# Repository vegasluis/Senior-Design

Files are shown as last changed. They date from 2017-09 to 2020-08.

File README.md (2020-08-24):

# Senior-Design

# Problem Identified
Pedestrian fatality rate is three times higher at night. Per the Traffic Safety Facts
(2012 Data), 70% of the pedestrians are killed in the nighttime (6PM – 5:59AM).
A driver can only avoid an accident if he/she sees the pedestrian relatively far
ahead. Headlights only let the driver see about 350 feet ahead.

# Current Solutions
The closest solution in the market is the innovative design Audi has incorporated
to their car model; the Audi A4 is more for personal use rather than a pubic
design. Crosswalk lighting on the street is available to light up sections of the
crosswalk once the light is pressed. Overhead flashing lights, like the Hawk
System, are also used with a set timer to warn drivers that pedestrians are trying
to cross. One tested solution is setting two posts on both sides of the street,
such that once a pedestrian presses a button, the lights turn on to illuminate the
crosswalk.

# Team’s Solution
The Pedestrian Lighting Guidance System is a more efficient way to solve
pedestrian fatalities due to poor visibility at night. The system will be very userfriendly. Pedestrians would not have to do anything different than they usually
do when crossing the street at night, because the pedestrian detection software
will control the spotlight whenever someone triggers it. The system will run
autonomously. The main detail of the
PLGS is its ability to view any object
crossing in the intersection using the
OpenCV libraries. The cameras process
the incoming images and relay the
position to the microprocessors that
control the motor servos, which rotate
180 degrees and will be able to move
the focused spotlights from one side of
the crosswalk to the other. The device
we are trying to create is optimized
more for industrial use, not for
consumer use. It does not require any
sort of reconstruction or modification
on the road.

# Youtube URL

https://www.youtube.com/watch?v=EUFnc7yAI7A

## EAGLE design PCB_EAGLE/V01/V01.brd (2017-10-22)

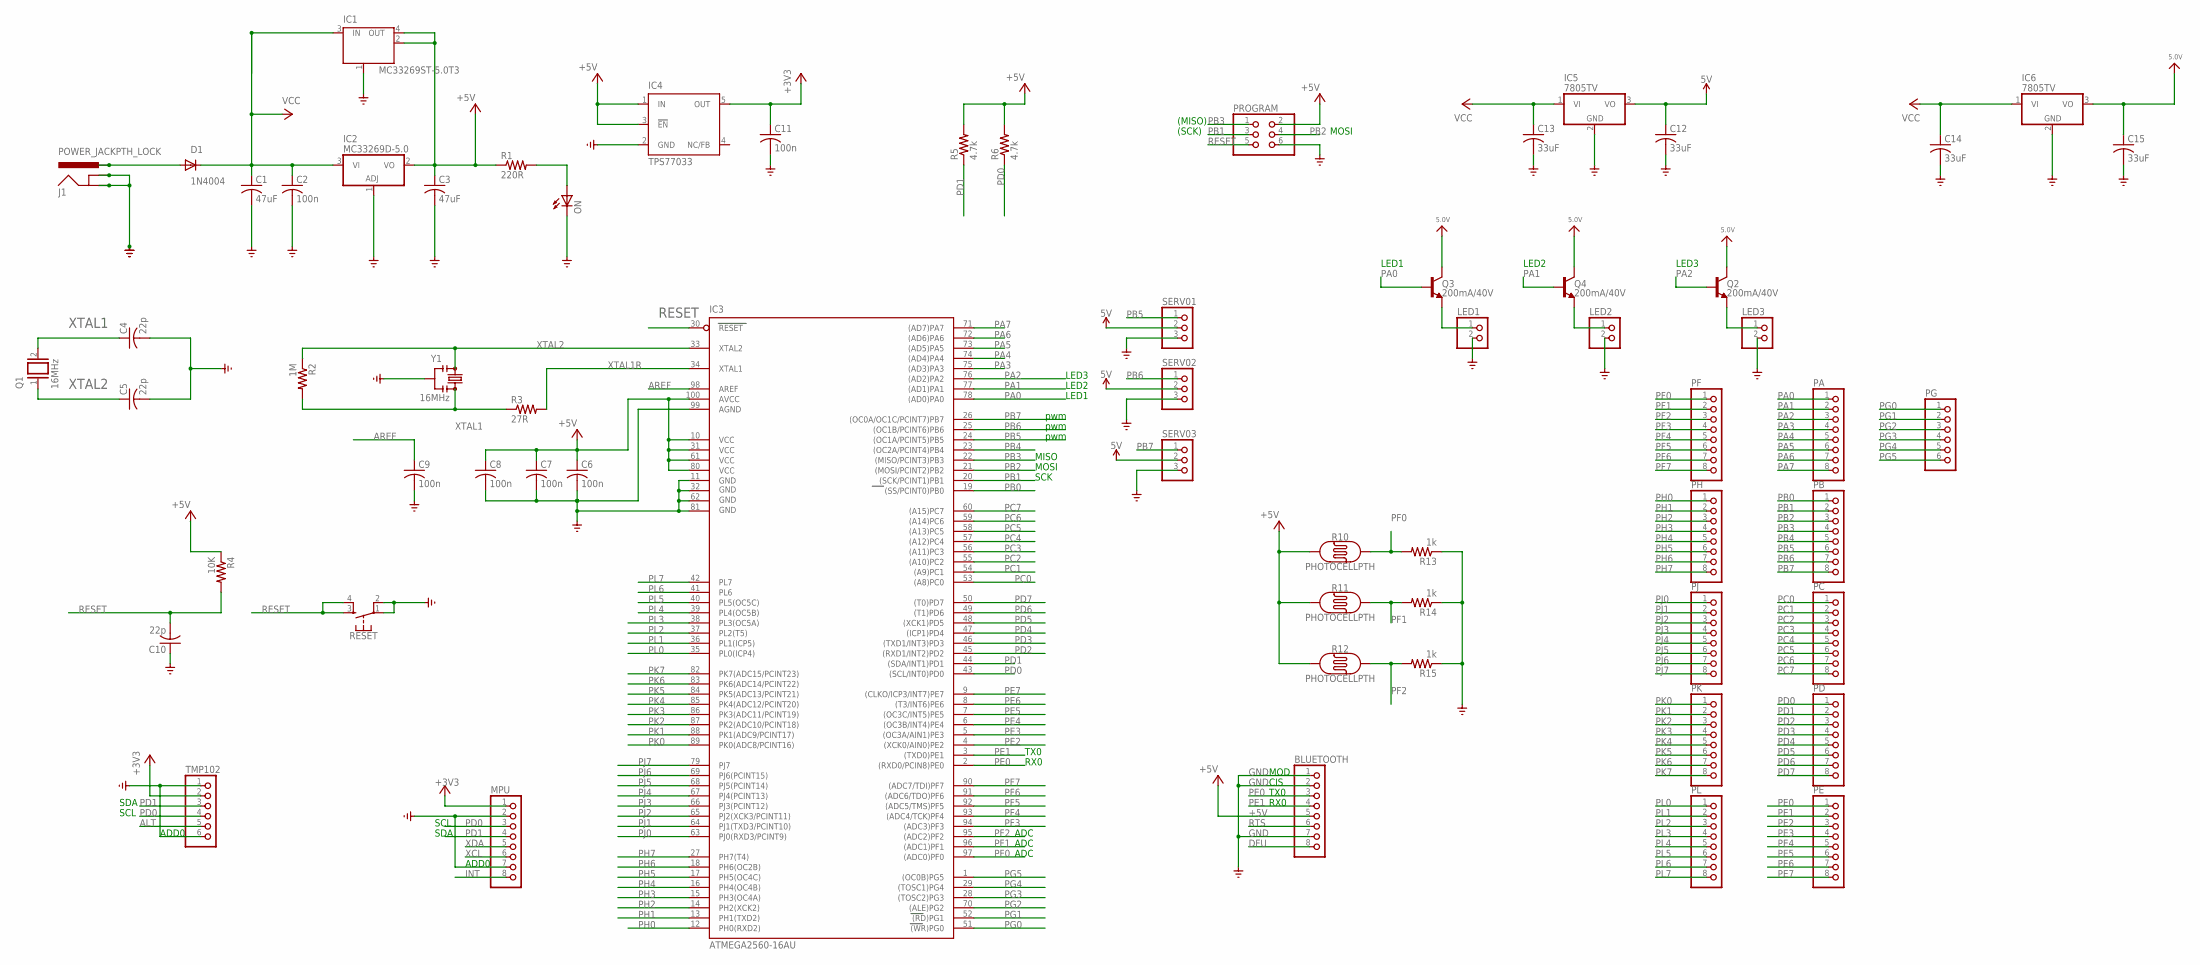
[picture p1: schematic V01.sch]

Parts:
BLUETOOTH: PINHD-1X8; 1X08
C1, C3: 47uF; C025-024X044
C2, C6, C7, C8, C9, C11: 100n; C025-024X044
C4, C5, C10: 22p; C025-024X044
C12, C13, C14, C15: 33uF; C025-024X044
D1: 1N4004; DO41-10
IC1: MC33269ST-5.0T3; SOT223
IC2: MC33269D-5.0; DPACK
IC3: ATMEGA2560-16AU; TQFP100
IC4: TPS77033; SOT23-DBV
IC5, IC6: 7805TV; TO220V
J1: POWER_JACKPTH_LOCK; POWER_JACK_PTH_LOCK
LED1, LED2, LED3: PINHD-1X2; 1X02
MPU: PINHD-1X8; 1X08
ON: LED3MM
PA: PINHD-1X8; 1X08
PB: PINHD-1X8; 1X08
PC: PINHD-1X8; 1X08
PD: PINHD-1X8; 1X08
PE: PINHD-1X8; 1X08
PF: PINHD-1X8; 1X08
PG: PINHD-1X6; 1X06
PH: PINHD-1X8; 1X08
PJ: PINHD-1X8; 1X08
PK: PINHD-1X8; 1X08
PL: PINHD-1X8; 1X08
PROGRAM: PINHD-2X3; 2X03
Q1: 16MHz; QS
Q2, Q3, Q4: 200mA/40V; TO-92
R1: 220R; 0204V
R2: 1M; 0204V
R3: 27R; 0204V
R4: 10K; 0204V
R5, R6: 4.7k; 0204V
R10, R11, R12: PHOTOCELLPTH; PHOTOCELL
R13, R14, R15: 1k; 0204V
RESET: MOMENTARY-SWITCH-SPST-2-SMD-5.2MM; TACTILE_SWITCH_SMD_5.2MM
SERV01, SERV02, SERV03: PINHD-1X3; 1X03
TMP102: PINHD-1X6; 1X06
Y1: 16MHz; RESONATOR-SMD-3.2X1.3

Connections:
5.0V: C15.1, IC6.3 (VO), Q2.3 (C), Q3.3 (C), Q4.3 (C)
5V: C12.1, IC5.3 (VO), SERV01.2, SERV02.2, SERV03.2
+3V3: C11.1, IC4.5 (OUT), MPU.1, TMP102.2
+5V: BLUETOOTH.5, C3.1, C6.1, C7.1, C8.1, IC1.2 (OUT), IC1.4 (OUT), IC2.2 (VO), IC3.10 (VCC), IC3.31 (VCC1), IC3.61 (VCC2), IC3.80 (VCC3), IC3.100 (AVCC), IC4.1 (IN), IC4.3 (!EN), PROGRAM.2, R1.1, R4.1, R5.2, R6.2, R10.1, R11.1, R12.1
ALT: TMP102.5
AREF: C9.1, IC3.98 (AREF)
DFU: BLUETOOTH.8
GND: BLUETOOTH.1, BLUETOOTH.2, BLUETOOTH.7, C1.2, C2.2, C3.2, C4.2, C5.2, C6.2, C7.2, C8.2, C9.2, C10.1, C11.2, C12.2, C13.2, C14.2, C15.2, IC1.1 (GND/ADJ), IC2.1 (ADJ), IC3.11 (GND), IC3.32 (GND1), IC3.62 (GND2), IC3.81 (GND3), IC3.99 (AGND), IC4.2 (GND), IC5.2 (GND), IC6.2 (GND), J1.GND, J1.GNDBREAK, LED1.2, LED2.2, LED3.2, MPU.2, MPU.7, ON.K (C), PROGRAM.6, R13.1, R14.1, R15.1, RESET.1, RESET.2, SERV01.3, SERV02.3, SERV03.3, TMP102.1, TMP102.6, Y1.2
INT: MPU.8
unnamed: ON.A, R1.2
unnamed: LED1.1, Q3.1 (E)
unnamed: LED2.1, Q4.1 (E)
unnamed: LED3.1, Q2.1 (E)
PA0: IC3.78 ((AD0)PA0), PA.1, Q3.2 (B)
PA1: IC3.77 ((AD1)PA1), PA.2, Q4.2 (B)
PA2: IC3.76 ((AD2)PA2), PA.3, Q2.2 (B)
PA3: IC3.75 ((AD3)PA3), PA.4
PA4: IC3.74 ((AD4)PA4), PA.5
PA5: IC3.73 ((AD5)PA5), PA.6
PA6: IC3.72 ((AD6)PA6), PA.7
PA7: IC3.71 ((AD7)PA7), PA.8
PB0: IC3.19 ((SS/PCINT0)PB0), PB.1
PB1: IC3.20 ((SCK/PCINT1)PB1), PB.2, PROGRAM.3
PB2: IC3.21 ((MOSI/PCINT2)PB2), PB.3, PROGRAM.4
PB3: IC3.22 ((MISO/PCINT3)PB3), PB.4, PROGRAM.1
PB4: IC3.23 ((OC2A/PCINT4)PB4), PB.5
PB5: IC3.24 ((OC1A/PCINT5)PB5), PB.6, SERV01.1
PB6: IC3.25 ((OC1B/PCINT6)PB6), PB.7, SERV02.1
PB7: IC3.26 ((OC0A/OC1C/PCINT7)PB7), PB.8, SERV03.1
PC0: IC3.53 ((A8)PC0), PC.1
PC1: IC3.54 ((A9)PC1), PC.2
PC2: IC3.55 ((A10)PC2), PC.3
PC3: IC3.56 ((A11)PC3), PC.4
PC4: IC3.57 ((A12)PC4), PC.5
PC5: IC3.58 ((A13)PC5), PC.6
PC6: IC3.59 ((A14)PC6), PC.7
PC7: IC3.60 ((A15)PC7), PC.8
PD0: IC3.43 ((SCL/INT0)PD0), MPU.3, PD.1, R6.1, TMP102.4
PD1: IC3.44 ((SDA/INT1)PD1), MPU.4, PD.2, R5.1, TMP102.3
PD2: IC3.45 ((RXD1/INT2)PD2), PD.3
PD3: IC3.46 ((TXD1/INT3)PD3), PD.4
PD4: IC3.47 ((ICP1)PD4), PD.5
PD5: IC3.48 ((XCK1)PD5), PD.6
PD6: IC3.49 ((T1)PD6), PD.7
PD7: IC3.50 ((T0)PD7), PD.8
PE0: BLUETOOTH.3, IC3.2 ((RXD0/PCIN8)PE0), PE.1
PE1: BLUETOOTH.4, IC3.3 ((TXD0)PE1), PE.2
PE2: IC3.4 ((XCK0/AIN0)PE2), PE.3
PE3: IC3.5 ((OC3A/AIN1)PE3), PE.4
PE4: IC3.6 ((OC3B/INT4)PE4), PE.5
PE5: IC3.7 ((OC3C/INT5)PE5), PE.6
PE6: IC3.8 ((T3/INT6)PE6), PE.7
PE7: IC3.9 ((CLKO/ICP3/INT7)PE7), PE.8
PF0: IC3.97 ((ADC0)PF0), PF.1, R10.2, R13.2
PF1: IC3.96 ((ADC1)PF1), PF.2, R11.2, R14.2
PF2: IC3.95 ((ADC2)PF2), PF.3, R12.2, R15.2
PF3: IC3.94 ((ADC3)PF3), PF.4
PF4: IC3.93 ((ADC4/TCK)PF4), PF.5
PF5: IC3.92 ((ADC5/TMS)PF5), PF.6
PF6: IC3.91 ((ADC6/TDO)PF6), PF.7
PF7: IC3.90 ((ADC7/TDI)PF7), PF.8
PG0: IC3.51 ((WR)PG0), PG.1
PG1: IC3.52 ((RD)PG1), PG.2
PG2: IC3.70 ((ALE)PG2), PG.3
PG3: IC3.28 ((TOSC2)PG3), PG.4
PG4: IC3.29 ((TOSC1)PG4), PG.5
PG5: IC3.1 ((OC0B)PG5), PG.6
PH0: IC3.12 (PH0(RXD2)), PH.1
PH1: IC3.13 (PH1(TXD2)), PH.2
PH2: IC3.14 (PH2(XCK2)), PH.3
PH3: IC3.15 (PH3(OC4A)), PH.4
PH4: IC3.16 (PH4(OC4B)), PH.5
PH5: IC3.17 (PH5(OC4C)), PH.6
PH6: IC3.18 (PH6(OC2B)), PH.7
PH7: IC3.27 (PH7(T4)), PH.8
PJ0: IC3.63 (PJ0(RXD3/PCINT9)), PJ.1
PJ1: IC3.64 (PJ1(TXD3/PCINT10)), PJ.2
PJ2: IC3.65 (PJ2(XCK3/PCINT11)), PJ.3
PJ3: IC3.66 (PJ3(PCINT12)), PJ.4
PJ4: IC3.67 (PJ4(PCINT13)), PJ.5
PJ5: IC3.68 (PJ5(PCINT14)), PJ.6
PJ6: IC3.69 (PJ6(PCINT15)), PJ.7
PJ7: IC3.79 (PJ7), PJ.8
PK0: IC3.89 (PK0(ADC8/PCINT16)), PK.1
PK1: IC3.88 (PK1(ADC9/PCINT17)), PK.2
PK2: IC3.87 (PK2(ADC10/PCINT18)), PK.3
PK3: IC3.86 (PK3(ADC11/PCINT19)), PK.4
PK4: IC3.85 (PK4(ADC12/PCINT20)), PK.5
PK5: IC3.84 (PK5(ADC13/PCINT21)), PK.6
PK6: IC3.83 (PK6(ADC14/PCINT22)), PK.7
PK7: IC3.82 (PK7(ADC15/PCINT23)), PK.8
PL0: IC3.35 (PL0(ICP4)), PL.1
PL1: IC3.36 (PL1(ICP5)), PL.2
PL2: IC3.37 (PL2(T5)), PL.3
PL3: IC3.38 (PL3(OC5A)), PL.4
PL4: IC3.39 (PL4(OC5B)), PL.5
PL5: IC3.40 (PL5(OC5C)), PL.6
PL6: IC3.41 (PL6), PL.7
PL7: IC3.42 (PL7), PL.8
POWERIN: D1.A, J1.PWR
RESET: C10.2, IC3.30 (RESET), PROGRAM.5, R4.2, RESET.3, RESET.4
RTS: BLUETOOTH.6
VCC: C1.1, C2.1, C13.1, C14.1, D1.C, IC1.3 (IN), IC2.3 (VI), IC5.1 (VI), IC6.1 (VI)
XCL: MPU.6
XDA: MPU.5
XTAL1: C4.1, Q1.2, R2.2, R3.1, Y1.3
XTAL1R: IC3.34 (XTAL1), R3.2
XTAL2: C5.1, IC3.33 (XTAL2), Q1.1, R2.1, Y1.1

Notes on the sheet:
pwm
ADD0
ADC
(MISO)
(SCK)
MOSI
MISO
SCK
TX0
RX0
SDA
SCL
MOD
CIS
LED1
LED2
LED3

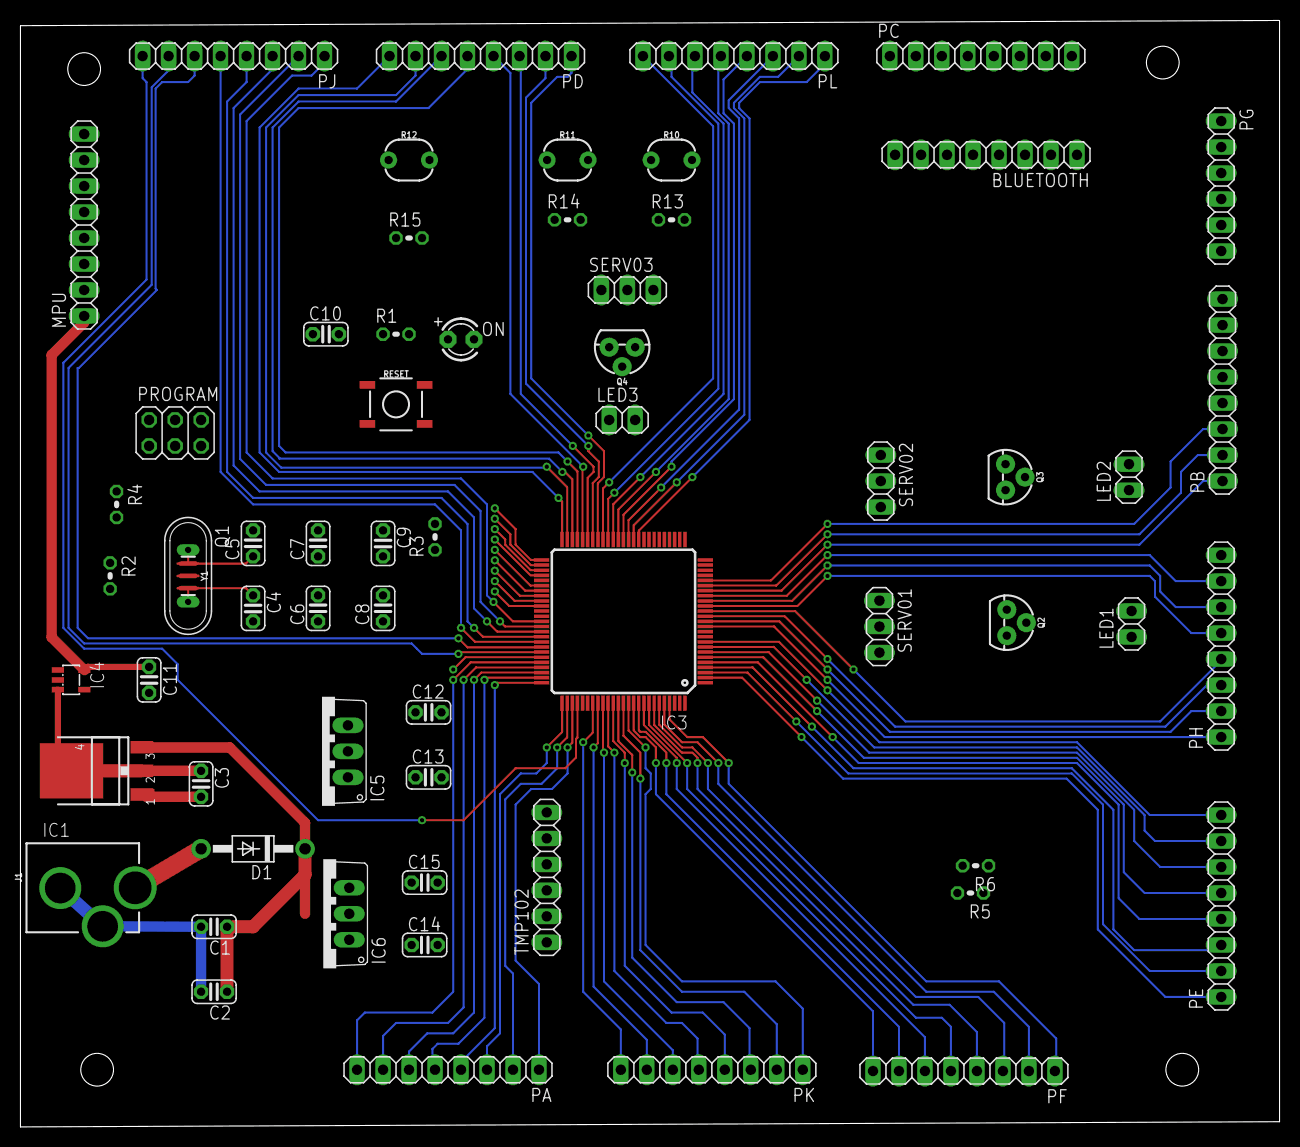
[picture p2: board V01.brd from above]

Board: 2 copper layers, 123.0 x 108.1 mm, 63 parts (0 on the bottom side), 102 nets.

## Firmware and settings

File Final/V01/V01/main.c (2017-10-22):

/*
 * V01.c
 *
 * Created: 8/30/2017 7:31:48 PM
 * Author : Luis
 */ 

#define F_CPU 16000000UL
#include <avr/io.h>
#include <avr/sleep.h>
#include <avr/power.h>
#include <avr/wdt.h>
#include <avr/interrupt.h>
#include <stdlib.h>
#include <stdio.h>
#include <stdint.h>
#include <util/atomic.h>
#include <util/delay.h>
#include "Drivers/timer1_16b.h"
#include "Drivers/uart0.h"
#include "Drivers/i2c_master.h"
#include "Drivers/mpu6050_reg.h"
#include "Drivers/mpu6050.h"
#include "Drivers/adc.h"
#include "Drivers/TMP102.h"

//*******************************************************
//Initalize before main 
void startUp(void)__attribute__((naked))__attribute__((section(".init3")));
uint8_t mcusr_mirror __attribute__ ((section (".noinit")));

//*******************************************************
//Watchdog 
#define soft_reset()		\
do                  		\
{							\
	cli();					\
	wdt_disable();			\
	wdt_enable(WDTO_15MS);	\
	while(1);				\
}while(0)		
		

//*******************************************************
//SERVO
/*	
	TC1 Clk = 16e6/64 = 250000UL (4us period)
	3001HB: SERVO_MIN 97(388us/4us), SERVO MAX 535 (2140us/4us)
	TGY-R5180MG: MAX RANGE 595(2380us) MIN RANGE 177 (708us)
		Values Used: SERVO_MIN will be our 0 deg and SERVO MAX will be our 180 deg 
 */
	 #define SERVO_MIN 150	
	 #define SERVO_MAX 640

	//-----------------
	//Functions 
	void setServos(volatile char* readString);
	volatile uint16_t getAngle (char firstInt, char secondInt, char thirdInt);
	volatile uint16_t getServoPos(volatile  uint16_t angle);
	void LED_state (char servoNum, char on);
	void clearReadString(void);

	//------------------
	//Variables need for Servo 
	volatile uint8_t charCount = 0;
	volatile char readString[20] = {0}; 

//*******************************************************
//Accelerometer 
	//-------------
	//Functions 
	const int readAccel();

//*******************************************************
//Tempature 
	volatile int temp = 0;

//********************************************************
//Watchdog 
void initWatchdog(void); 

//Sleep Function
void enterSleep(void);
void aboutToSleep(void);

//Use to count a certain number of ticks
volatile int countTick  __attribute__ ((section (".noinit")));

//ADC
volatile double valueADC0,valueADC1,valueADC2;


//********************************************************
//MAIN 

int main(void)
{
	printm_0("Welcome!!!\r\n");
	
	//initate global interrupts
	sei(); 
	
	while(1);

	return 0;
}

//-------------------------------------------------------
//UART0_ ISR 
ISR (USART0_RX_vect)
{
	ATOMIC_BLOCK(ATOMIC_FORCEON)
	{
		unsigned char receivedChar;
		receivedChar = UDR0;							// Read data from the RX buffer
		putChar_0(receivedChar);
		//_delay_ms(2);
		_delay_us(700);

		
		//READ in char and append to end char array
		/*
		 * Format to be read in:
		 * 1 1 000 2 1 000 3 1 000
		 * S L ANG S L ANG S L ANG
		 * S: Servo, L: LED State, ANG: Angle
		 */
		
		readString[charCount] = receivedChar;
		++charCount;
		 
		if(charCount >= 15 || receivedChar == '\0')
		{	
			printm_0("\r\n");   
			printm_0("Read String: ");
			printm_0(readString);
			printm_0("\r\n");

			if(receivedChar != '\0')
			{
				temp = getTemp();
				printm_0("Temp: ");
				print_int_0(temp);
				printm_0(" C*\r\n");
				if(temp > 50 || temp < -10)	
				{
					printm_0("AYY Caliente!!\r\n");
					aboutToSleep();
					initWatchdog();
					enterSleep();
				}	

				if(readAccel() != 1) setServos(readString); 
			}
			
			charCount = 0;
			clearReadString();
		}
		UART_0_flush();
	}
}

ISR(WDT_vect)
{
	soft_reset();
}

ISR(TIMER1_OVF_vect)
{ 
	++countTick;
	if(countTick > 1000)
	{	
		startADC0();
		waitADC();
		valueADC0 = (ADCW *5 / 1024.0);
		printm_0("Voltage 1 Level Read: ");
		print_double_0(valueADC0);
		printm_0("\r\n");

		startADC1();
		waitADC();
		valueADC1 = (ADCW *5 / 1024.0);
		printm_0("Voltage 2 Level Read: ");
		print_double_0(valueADC1);
		printm_0("\r\n");

		startADC2();
		waitADC();
		valueADC2 = (ADCW *5 / 1024.0);
		printm_0("Voltage 3 Level Read: ");
		print_double_0(valueADC2);
		printm_0("\r\n");

		//REMOVE AFTER TESTING
		//_delay_ms(1000);

		//If there is light outside the voltage leve increases as the resitance 
		//in the photo diode increases
		/*
			R2 = Resistor
			R1 = Photo Diode 
			Vin(R2/(R1+R2))
		*/
		if((valueADC0 > 1.50 && valueADC1 > 1.50) 
			|| (valueADC1 > 1.50 && valueADC2 > 1.50)
			 || (valueADC0 > 1.50 && valueADC2 > 1.50))
		{
			initWatchdog();
			aboutToSleep();
			enterSleep();
		}
		countTick = 0;
	}
}
//**********************
//Servo Function body Implementation 

/*
 *Arguments: a string consisting of 3 servos, 3 LEDs , and
 *3 distinct angles
 *Format of Argument String: 1 1 000 2 1 000 3 1 000
 */
void setServos(volatile char* readString)
{ 
	uint16_t servoPosVal = 0; 

 	//SERVO 1 
 	//readString[0] == Servo 1
 	//read String[1] == ON/OFF state
 	LED_state(readString[0],readString[1]);
 	servoPosVal = getServoPos(getAngle(readString[2],readString[3],readString[4]));
 	if(servoPosVal < SERVO_MIN) OCR1A = SERVO_MIN;
 	else if (servoPosVal > SERVO_MAX) OCR1A = SERVO_MAX;
 	else OCR1A = servoPosVal;

 	//SERVO2
 	//readString[5] == Servo 1
 	//read String[6] == ON/OFF state
 	LED_state(readString[5],readString[6]);
 	servoPosVal = getServoPos(getAngle(readString[7],readString[8],readString[9]));
 	if(servoPosVal < SERVO_MIN) OCR1B = SERVO_MIN;
 	else if (servoPosVal > SERVO_MAX) OCR1B = SERVO_MAX;
 	else OCR1B = servoPosVal;

 	//SERVO3
 	//readString[10] == Servo 1
 	//read String[11] == ON/OFF state
 	LED_state(readString[10],readString[11]);
 	servoPosVal = getServoPos(getAngle(readString[12],readString[13],readString[14]));
 	if(servoPosVal < SERVO_MIN) OCR1C = SERVO_MIN;
 	else if (servoPosVal > SERVO_MAX) OCR1C = SERVO_MAX;
 	else OCR1C = servoPosVal;
}
/* Return an integer value that represents and angle 
 * An angle between 0 - 180
 */
volatile uint16_t getAngle (char firstInt, char secondInt, char thirdInt)
{
	uint16_t sum = 0;
	sum =  (firstInt - 0x30)*100;
	sum += (secondInt - 0x30)*10;
	sum += (thirdInt - 0x30);
	return sum;
}
/* 
 * Argument: unsigned char, that represents an angle between 0-180
 * Return an integer that will represent a certain duty cycle
 */
volatile uint16_t getServoPos(uint16_t angle)
{
	uint16_t servoVal = 0;
	servoVal = (uint16_t) ((((float)angle)/180.0)*490.0)+150.0;
	return servoVal;
}
/*
 * Change the respeceted LED state
 */
void LED_state(char servoNum, char on)
{
	switch(servoNum){
		case '1': 
		{
			if(on == '1') PORTA |= (1<<PA0);
			else PORTA &= ~(1<<PA0);
			break;
		}
		case '2':
		{
			if(on == '1') PORTA |= (1<<PA1);
			else PORTA &= ~(1<<PA1);
			break;
		}
		case '3':
		{
			if(on == '1') PORTA |= (1<<PA2);
			else PORTA &= ~(1<<PA2);
			break;
		}
		default:printm_0("Servo Number does not exist\r\n");break;
	}

}

//**************
//Accelerometer Function body Implementation 

/* 
   Read the X,Y, and Z components off the accelerometer 
 */
const int readAccel() 
{

	int16_t accel_buff[3];
	double accelX, accelY, accelZ;
	//**********************************************
	//MPU6050

	//Read all axis of the accelerator's
	mpu6050_read_accel_ALL(accel_buff);
	mpu6050_read_accel_ALL(accel_buff);
	
	// acceleration (m/s^2)
	// Sensitivity 16384 LSB/g
	// +/- 2g full scale range
	accelX = accel_buff[0]*9.8*2/32768;
	accelY = accel_buff[1]*9.8*2/32768;
	accelZ = accel_buff[2]*9.8*2/32768;

	//printInfo
	printm_0("AccelX: ");
	print_double_0(accelX);
	printm_0("\r\n");
	printm_0("AccelY: ");
	print_double_0(accelY);
	printm_0("\r\n");
	printm_0("AccelZ: ");
	print_double_0(accelZ);
	printm_0("\r\n");


	/*
	 * Go in if not stable enough and return one 
	 * The Servo will stay a constant position until stable enough
	 * to do some image processing
	 */

	if(accelX >= 15 || accelX <= -15 || accelY >= 15 ||
		accelY <= -15 || accelZ >= 15 || accelZ <= -15)
	{
		printm_0("Put servo in standstill mode\r\n");
		PORTA |= (1<<PA0)|(1<<PA1)|(1<<PA2);
		/*
		 * Angles set later 
		 */
		OCR1A = getServoPos((uint16_t)45);
		OCR1B = getServoPos((uint16_t)90);
		OCR1C = getServoPos((uint16_t)125);
		return 1;
	}

	return 0;
}

/*
 * Function is intended to set all reg needed before main 
 */
void startUp(void)
{
	//Disable Watchdog and Reset the MCU Status Reg
	//Incase of any Resets
	mcusr_mirror = MCUSR;
	MCUSR = 0;
    wdt_disable();

	//**************************************************
	//UART0
	uart0_int();

	//If the System has been reset notify the other system
	if(mcusr_mirror > 0) printm_0("Reseting \r\n");
	
	//set interrupt flag UART0
	RX_INTEN_0();

	//**************************************************
	//ADC
	intiateADC();

	//**************************************************
	//TIMER/COUNTER1

	//initiate Timer1
	initateTimer1();

	//Initiate Timer/Counter 1 interrupts 
	OVERFLW_TC1();
 
	//**************************************************
	//SERVO

	//intial value 		
	OCR1A = SERVO_MIN;
	OCR1B = SERVO_MIN;
	OCR1C = SERVO_MIN;

	//LED
	//set as outputs
	DDRA |= (1<<PA0)|(1<<PA1)|(1<<PA2);

	//**************************************************
	//I2C

	//Iniate i2c protocol 
	i2c_init();

	//Set SCL and SDA as in Inputs
	DDRD &= (0<<PD0)|(0<<PD1); 

	//Pull UP 
	PORTD |= (1<<PD0)|(1<<PD1); 
	
	//**************************************************
	//MPU6050

	//initate MPU6050
	i2c_start(MPU6050_ADDRESS+I2C_WRITE); 
	mpu6050_init();

	//**************************************************

	countTick = 0;
} 

void initWatchdog(void)
{ 
  /* In order to change WDE or the prescaler, we need to
   * set WDCE (This will allow updates for 4 clock cycles).
   */
  WDTCSR |= (1<<WDCE) | (1<<WDE);

  /* set new watchdog timeout prescaler value */
  WDTCSR = 1<<WDP0 | 1<<WDP3; /* 8.0 seconds */
  
  /* Enable the WD interrupt (note no reset). */
  WDTCSR |= _BV(WDIE);  
} 

void enterSleep(void)
{
	cli();
	printm_0("About to go to Sleep\r\n");

	set_sleep_mode(SLEEP_MODE_PWR_DOWN);
	sleep_enable();

	sei();
	/* Now enter sleep mode. */
	sleep_cpu();

	sleep_disable(); /* First thing to do is disable sleep. */
	
	/* Re-enable the peripherals. */
  	power_all_enable();
}

void aboutToSleep(void)
{
	for(int i = 0; i < 10; ++i)
	{
		printm_0("inloop\r\n");
		PORTA |= (1<<PA0|1<<PA1|1<<PA2);
		_delay_ms(2500);
		PORTA = 0X0;
		_delay_ms(2500);
	}
	PORTA &= (0<<PA0)|(0<<PA1)|(0<<PA2);
}

void clearReadString(void)
{
	for(int i = 0; i < 20; ++i)
		readString[i] = "\0";
}

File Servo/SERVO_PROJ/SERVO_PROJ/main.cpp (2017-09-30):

/*
 * SERVO_PROJ.cpp
 *
 * Created: 8/18/2017 4:47:09 PM
 * Author : Luis
 */ 

#define F_CPU 16000000UL
#ifndef BAUD
#define BAUD 9600
#endif
#include <avr/io.h>
#include "Drivers/timer1_16b.h"
#include "Drivers/uart0.h"
#include <stdlib.h>
#include <stdio.h>
#include <util/setbaud.h>
#include <avr/interrupt.h>
#include <util/delay.h>
#include <stdint.h>
#include <inttypes.h>

using namespace std;
//*******************************************************
//SERVO
/*	
	TC1 Clk = 16e6/64 = 250000UL (4us period)
	3001HB: SERVO_MIN 97(388us/4us), SERVO MAX 535 (2140us/4us)
	TGY-R5180MG: MAX RANGE 595(2380us) MIN RANGE 177 (708us)
		Values Used: SERVO_MIN will be our 0 deg and SERVO MAX will be our 180 deg 
 */
 #define SERVO_MIN 245	
 #define SERVO_MAX 505

 uint8_t position[6] = {0};

 int getInt(volatile unsigned char *position);
 int getServoposition(int);


int main(void)
{
	//initiate UART0
	uart0_int();

	//initiate Timer1
	initateTimer1();
	//**************************************************
	//SERVO 

	//intial value 		
	OCR1A = SERVO_MIN;
	OCR1B = SERVO_MIN;
	OCR1C = SERVO_MIN;

    while (1) 
    {
		uint8_t servo;
    	int position_int = 0;

    	printm_0("\r\nPlease Enter Servo you Wish to Move(1-3):");
    	servo = getChar_0();
		print_int_0((servo - 0x30));
		UART_0_flush();

    	printm_0("\r\nPlease Enter at what angle to move it to (between 0 - 180):");
    	scanm_0(position);
		putChar_0(' ');
		print_int_0(getInt(position));

    	position_int = getServoposition(getInt(position));

		printm_0("\r\nAngle Converted to a desired Duty Cycle:");
		print_int_0(position_int);

    	printm_0("\r\n");

    	switch(servo)
    	{
    		case '1':
    		{
    			if(position_int < SERVO_MIN)
					OCR1A = SERVO_MIN;
				else if(position_int > SERVO_MAX)
					OCR1A = SERVO_MAX;
				else 
					OCR1A = (uint16_t)position_int;
					
    			break;
    		}
    		case '2':
    		{
    			if(position_int < SERVO_MIN)
					OCR1B = SERVO_MIN;
				else if(position_int > SERVO_MAX)
					OCR1B = SERVO_MAX;
				else
					OCR1B = position_int;

    			break;
    		}
    		case '3':
    		{
    			if(position_int < SERVO_MIN)
					OCR1C = SERVO_MIN;
				else if(position_int > SERVO_MAX)
					OCR1C = SERVO_MAX;
				else
					OCR1C = position_int;

    			break;
    		}
    		default: printm_0("\r\nPlease enter a valid Servo\r\n");break;
    	}

    }
}
//Get the integer value of a 3 digit number 
int getInt(volatile unsigned char *position)
{
	int sum = 0;
	sum =  (position[0]-0x30)*100;
	sum += (position[1]-0x30)*10;
	sum += (position[2]-0x30);
	return sum;
}//getInt

//Based on the angle passed in return a duty cycle value
int getServoposition(int val){
	int servoVal = 0;
	servoVal = (int) ((((float)val)/180.0)*260.0)+245.0;
	return servoVal;
}//getServoposition

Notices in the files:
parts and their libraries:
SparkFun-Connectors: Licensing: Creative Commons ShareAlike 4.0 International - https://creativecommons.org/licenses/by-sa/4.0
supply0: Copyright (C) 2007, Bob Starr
